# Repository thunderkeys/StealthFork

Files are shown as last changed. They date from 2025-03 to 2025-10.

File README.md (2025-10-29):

# Stealth Fork (Beta)  

<p align="center">
The one where Micron R1 & Salad Fork had a baby...
</p>

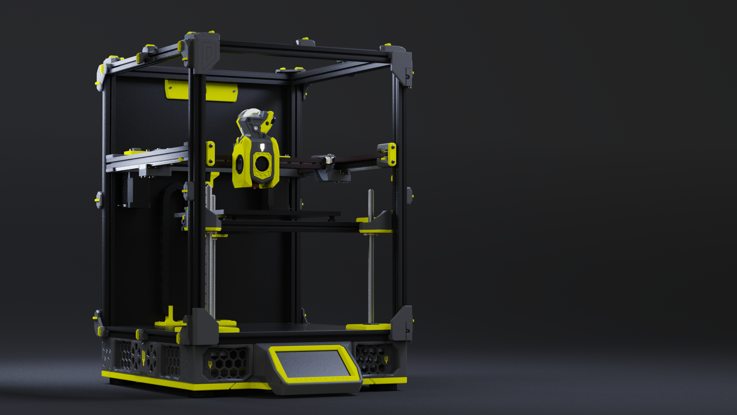
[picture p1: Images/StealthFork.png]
Rendering of a StealthFork


<p align="center">
  <a aria-label="Stars" href="https://github.com/PrintersForAnts/StealthFork/stargazers">
    </a> &nbsp;
    
  <a aria-label="Forks" href="https://github.com/PrintersForAnts/StealthFork/network/members">
    </a> &nbsp;
    
  <a aria-label="License" href="https://github.com/PrintersForAnts/StealthFork/blob/main/LICENSE">
    </a> &nbsp;
    
  <a aria-label="Commits" href="https://github.com/PrintersForAnts/StealthFork/commits/main">
    </a> &nbsp;
    
  <a aria-label="Discord" href="https://discord.gg/doomcube">
    </a>
</p>

## About  

Stealth Fork is an experimental design that blends the awesome aesthetic and compact form factor of the [**Micron+ R1**](https://github.com/PrintersForAnts/Micron/tree/main) with the fixed gantry of the [**Salad Fork**.](https://github.com/PrintersForAnts/Salad_Fork) If you’ve ever wanted a machine that blends the best of both, this is it.  

### Additional Features Ported from Micron:
- Bottom panel as stock
- Dual shear add-ons for A/B motors
- Pinned variants of A/B & X/Y as stock
- Optimised belt path
- Larger feet for more stability
- 3.5-inch / 4.3-inch display mounts as stock
- 2x Keystone mounts in rear skirt
- Stealthy aesthetics

> **Note:** This repository is a work in progress. I'll be updating it as things evolve. The goal is a seamless build experience, without compromising the high standards of either parent design.  

---

## Current Status  

- ✅ **STLs Uploaded** – All required STLs for a 180mm or 160mm build are included.
- 🔜 **CAD Files Coming Soon** – Once files are cleaned up, they'll be added (Skirt CAD files available).
- ⚠️ **Beta Release** – While all parts have been printed successfully, a full assembly is still pending. Expect minor refinements.

---

## Required Parts from Micron R1

Some parts are not included in this repo and need to be pulled directly from the **Micron R1 Repo** to convert your current Salad Fork. This is intended to prevent having to update several files that can be used for both printers. However, this may change and they all get uploaded here if it becomes too much of a pain based on feedback. 

| **Category** | **Micron R1 Repo Link** | **Required Parts** |
|---|---|---|
| **Panel Clips & Misc** | [Panels](https://github.com/PrintersForAnts/Micron/tree/main/STLs/Panels) | All except: Bowden Entry Accent Front Cover, Top Hinge Leaf |
| **X Axis** | [X Axis](https://github.com/PrintersForAnts/Micron/tree/main/STLs/Gantry/X_Axis) | All |
| **AB Double Shear Mounts** | [AB Drives](https://github.com/PrintersForAnts/Micron/tree/main/STLs/Gantry/AB_Drives/double_shear_mounts) | All |
| **Front Skirt Display Mounts** | [Skirt Displays](https://github.com/PrintersForAnts/Micron/tree/main/STLs/Skirts/Displays) | All except: Bezels |
| **Front Idler Carrier** | [Idler Carrier](https://github.com/PrintersForAnts/Micron/tree/main/STLs/Gantry/Idlers) | Screwed or Pinned available |

---

## Print Recommendations

**All STLs should be correctly oriented for printing.**

- **Material**: ABS or ASA
- **Infill**: 40% (Grid, Gyroid, Honeycomb, Triangle or Cubic)
- **Supports**: Not required
- **Layer Height**: 0.2mm (Including first layer)
- **Wall Count**: 4
- **Extrusion Width**: Forced 0.4mm
- **Solid Top/Bottom Layers**: 5

---

## BOM

A full BOM will be provided, but for now, the large differences are:

|**Item**|**Qty**|**Link**|**Notes**|
|---|---|---|---|
|Feet|x4|[Ali Express](https://s.click.aliexpress.com/e/_EJ0t67E)|
|Waveshare 4.3 Display|x1|[Ali Express](https://s.click.aliexpress.com/e/_EGOmTWc)|
|M5x20 BHCS|x4|[Ali Express](https://s.click.aliexpress.com/e/_ExQz6rS)|
|M3x8 BCHS|x40~|[Ali Express](https://s.click.aliexpress.com/e/_EyFT87W)|To replace M3x6 BHCS for skirt mounting, and replace M3x10 BHCS on gantry mounting.|
|M3x12 BHCS|x25~|[Ali Express](https://s.click.aliexpress.com/e/_Ew2GXKg)|For mounting bottom panel to skirts.|
|M3x25 BHCS|x3|[Ali Express](https://s.click.aliexpress.com/e/_ExoTSVa)|To mount skirt corners.|
|M3x20 BHCS|x1|[Ali Express](https://s.click.aliexpress.com/e/_Eu5EjP6)|To mount power inlet corner.|

---

## Feedback & Discussion  

If you're building a Stealth Fork, I'd love to hear your thoughts! 

Join the discussion, suggest improvements, or share feedback in the 'stealth_fork' channel on the Doomcube Discord.  

---

## Raising Issues

If you encounter any issues, please report them via the Issues section on the Git repository. 

Be as detailed as possible — include steps to reproduce and any relevant screenshots. 

Your feedback helps improve the Stealth Fork for everyone!

---

## Version History

| Date | Changes |
|---|---|
| 28-Oct-2025  | `[a]_Z_Bed_Mount_Front_L_x1.stl` & `[a]_Z_Bed_Mount_Front_R_x1.stl` updated to remove interferance with extrusion. |
| 27-Mar-2025  | Added STLs & CAD to convert Salad Fork rear panel to StealthFork Bowden entry. |
| 19-Mar-2025  | Fixed bottom panel DXFs. *(Thanks TurtleCrawler)* |
| 18-Mar-2025  | Uploaded bottom panel STLs & DXFs for 180mm & 160mm builds |
| 15-Mar-2025  | Uploaded 160mm skirt STLs<br>Uploaded 160_Skirts_v16.step<br>Uploaded 180_Skirts_v24.step<br>Added missing Rear_Centre_Skirt_Keystone_x1.stl (180mm) |
| 10-Mar-2025  | Initial release of beta STLs |

---

## Acknowledgements

- **HartK** for the awesome Micron  
- **Yeri** for the equally awesome Salad Fork
- **Thunderkeys** for his help with various STL issues

---

## Build Showcase

### **TurtleCrawler**

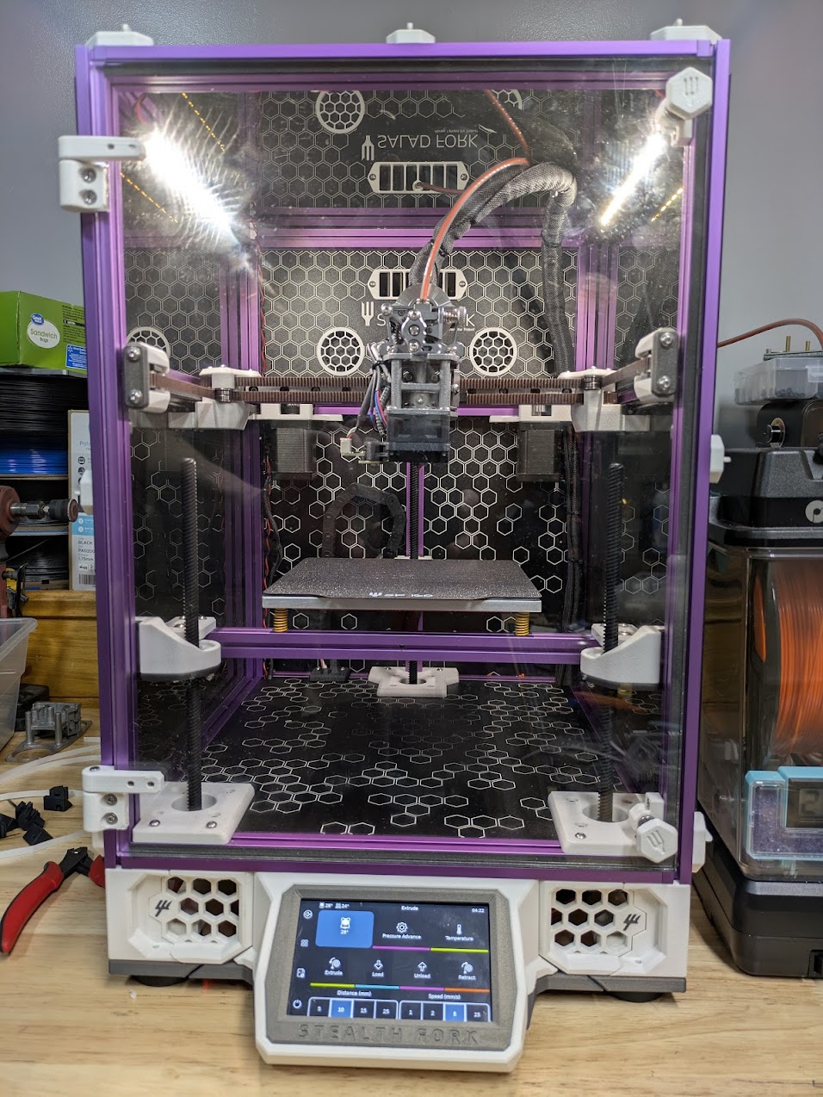
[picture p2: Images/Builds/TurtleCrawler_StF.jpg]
Turtlecrawler_StF


### **Thunderkeys**

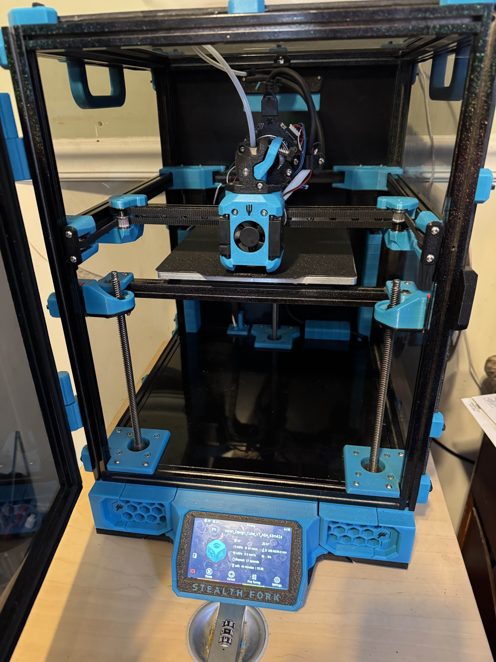
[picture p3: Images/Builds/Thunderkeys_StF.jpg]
Thunderkeys_StF


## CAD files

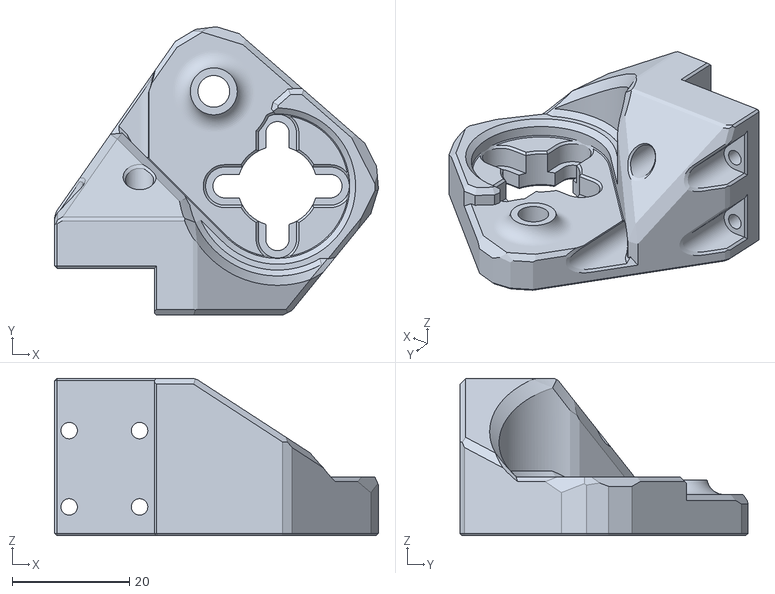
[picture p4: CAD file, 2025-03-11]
STLs/Z/Z_Carriage_Main_Left_x1.stl
55.2 x 49.2 x 26.8

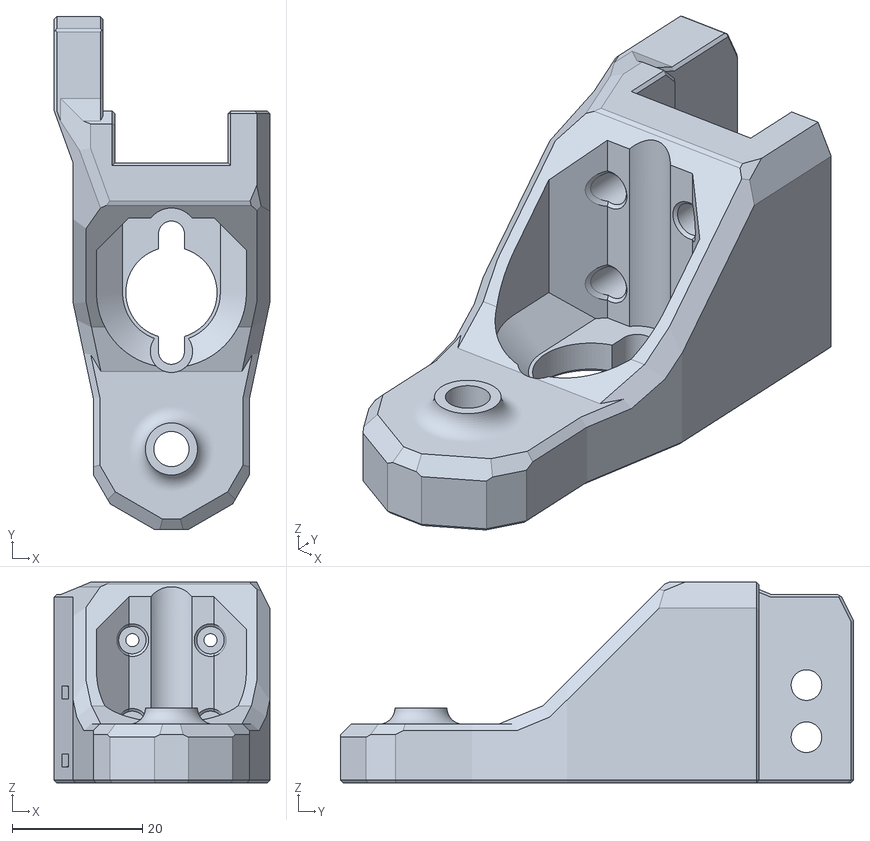
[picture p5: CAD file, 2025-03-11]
STLs/Z/Z_Carriage_Main_Rear_x1.stl
33.1 x 78.8 x 30.8

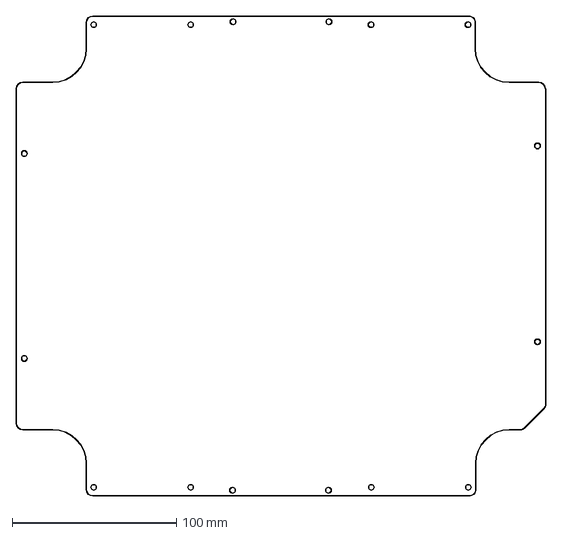
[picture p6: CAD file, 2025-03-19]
DXFs/160_Bottom_Panel.dxf
321.9 x 291.8 mm

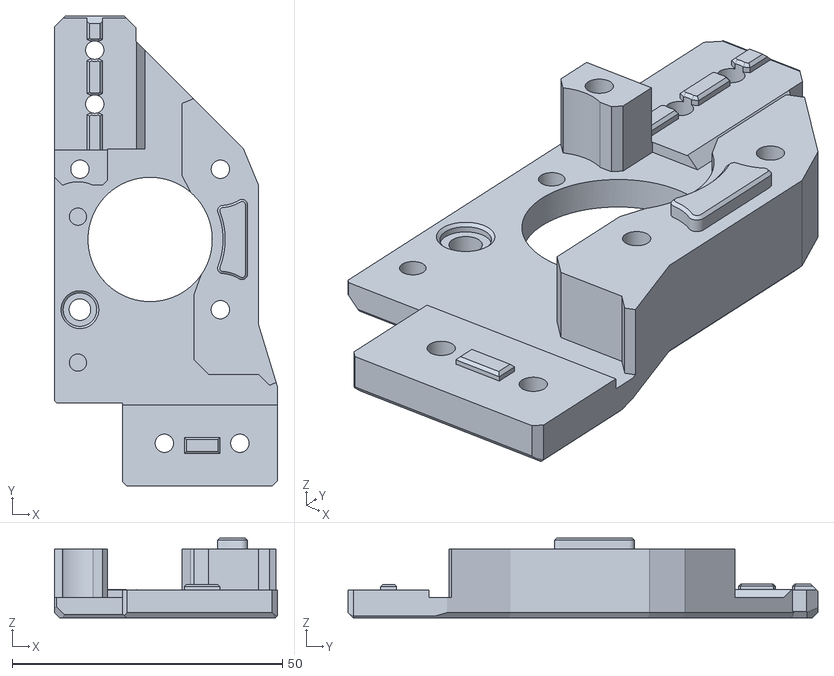
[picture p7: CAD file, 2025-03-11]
STLs/Gantry/A_B_Drives/B_Drive_Frame_Lower_Pinned.stl
41.3 x 87.0 x 14.8

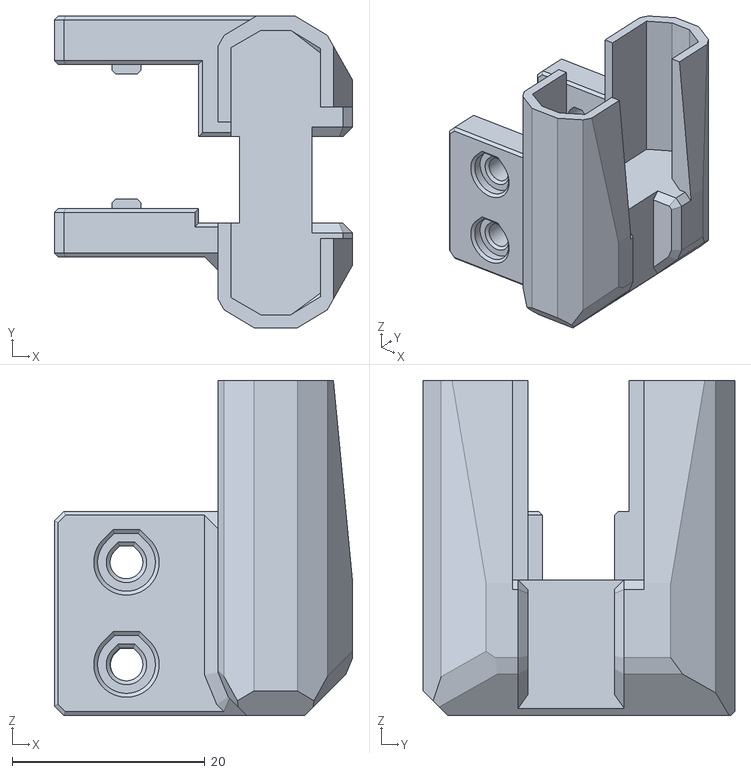
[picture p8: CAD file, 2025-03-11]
STLs/Gantry/Idler_Housing_x2.stl
31.0 x 32.4 x 34.8

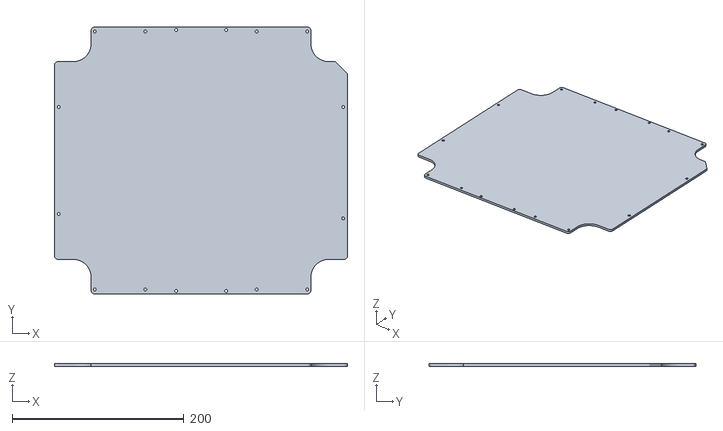
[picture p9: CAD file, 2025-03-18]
STLs/Panels/180_Bottom_Panel.stl
341.6 x 311.2 x 3.00

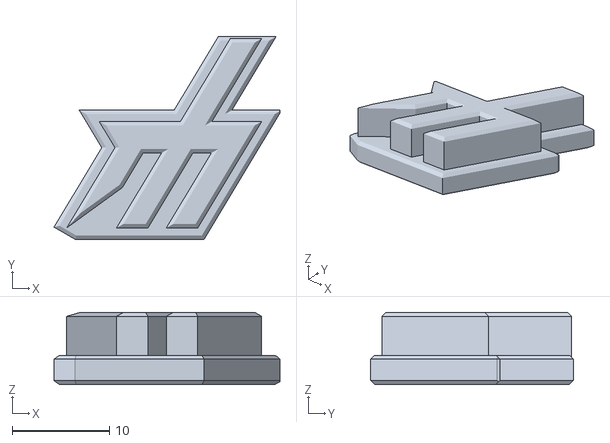
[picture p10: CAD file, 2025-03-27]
STLs/Panels/Salad Fork Rear Panel Conversion/Logo_Insert_x1.stl
23.2 x 20.8 x 7.40

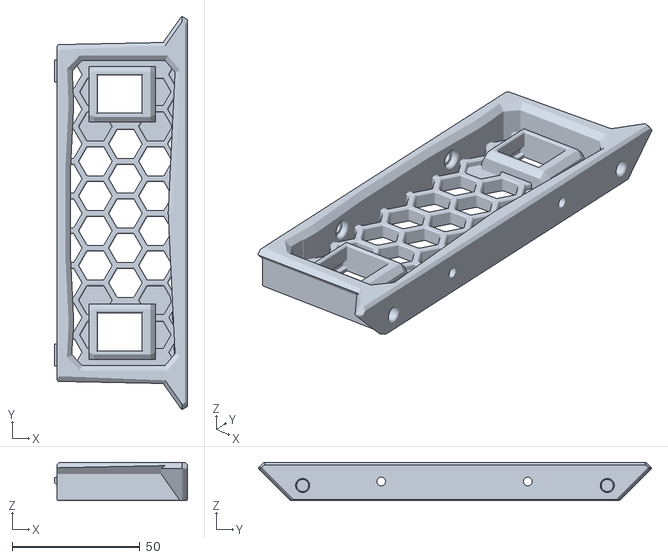
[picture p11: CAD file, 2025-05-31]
STLs/Skirts/160/160_Rear_Centre_Skirt_Keystone_x1.stl
52.0 x 153.8 x 15.0

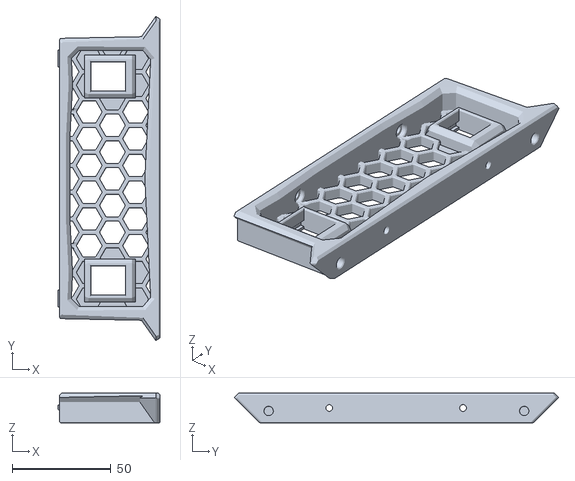
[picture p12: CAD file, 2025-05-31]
STLs/Skirts/180/Rear_Centre_Skirt_Keystone_x1.stl
52.0 x 164.4 x 15.0

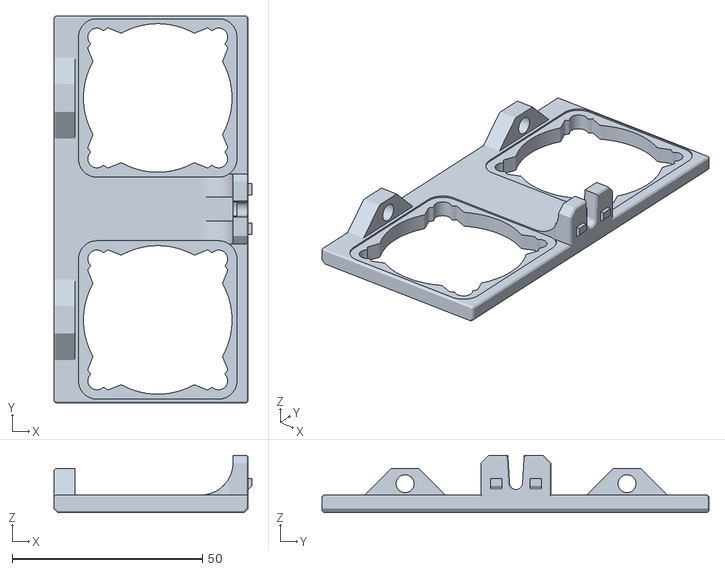
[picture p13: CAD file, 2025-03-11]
STLs/Skirts/Common STLs/Centre_Skirt_Fan_Mount_x2.stl
52.0 x 101.5 x 15.0

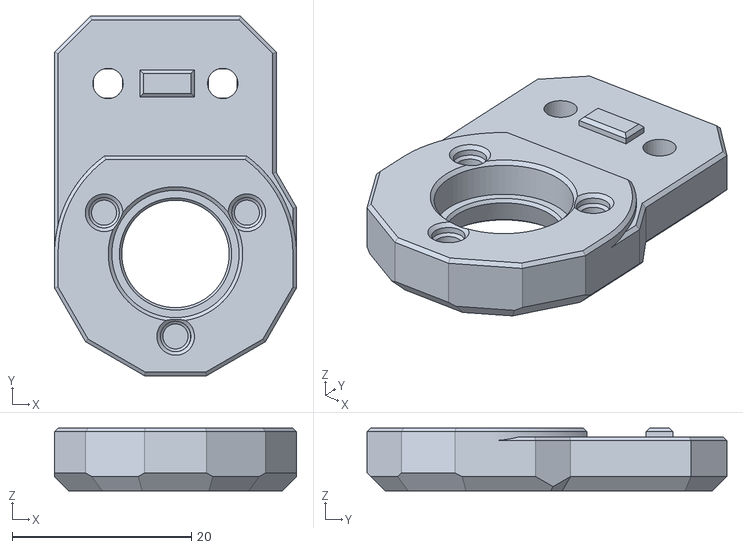
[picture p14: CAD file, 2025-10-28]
STLs/Z/[a]_Z_Bed_Mount_Front_L_x1.stl
27.0 x 40.1 x 7.00

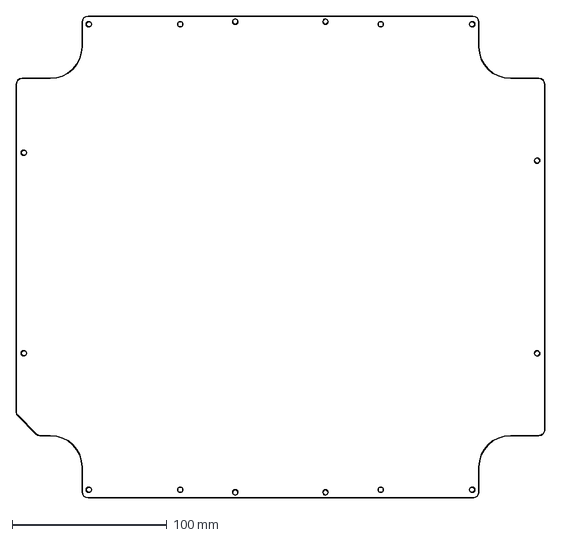
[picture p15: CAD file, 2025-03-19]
DXFs/180_Bottom_Panel.dxf
341.6 x 311.2 mm

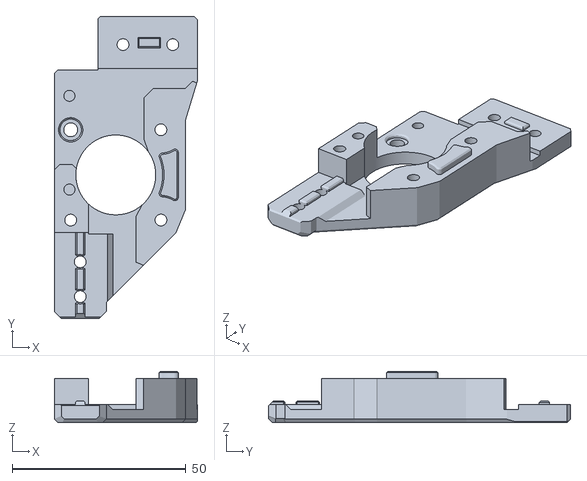
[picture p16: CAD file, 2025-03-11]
STLs/Gantry/A_B_Drives/A_Drive_Frame_Lower_Pinned.stl
41.3 x 87.0 x 14.8

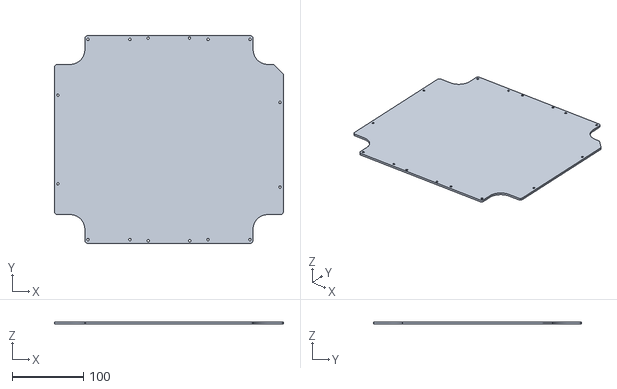
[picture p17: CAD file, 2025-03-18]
STLs/Panels/160_Bottom_Panel.stl
321.9 x 291.8 x 3.00

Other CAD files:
STLs/Z/Z_Carriage_Main_Right_x1.stl
STLs/Panels/Salad Fork Rear Panel Conversion/[a]_Bowden_Tube_Entry_Accent_Cover_x1.stl
STLs/Skirts/160/160_Corner_A_Front_Skirt _x1.stl
STLs/Skirts/180/[a]_Corner_B_Side_Skirt_Accent_x2.stl
STLs/Gantry/A_B_Drives/A_Drive_Frame_Lower_Screwed.stl
STLs/Gantry/A_B_Drives/A_Drive_Frame_Upper_Pinned.stl
STLs/Gantry/A_B_Drives/A_Drive_Frame_Upper_Screwed.stl
STLs/Gantry/A_B_Drives/B_Drive_Frame_Lower_Screwed.stl
STLs/Gantry/A_B_Drives/B_Drive_Frame_Upper_Pinned.stl
STLs/Gantry/A_B_Drives/B_Drive_Frame_Upper_Screwed.stl
STLs/Panels/Bowden_Entry_Logo_Insert_x1.stl
STLs/Panels/Salad Fork Rear Panel Conversion/Bowden Tube Entry Rear Cover Base_x1.stl
STLs/Panels/Salad Fork Rear Panel Conversion/Bowden Tube Entry Rear Cover ECAS_x1.stl
STLs/Panels/Salad Fork Rear Panel Conversion/Bowden Tube Entry Rear Cover M10_x1.stl
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

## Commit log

2025-03-11 Upload beta files
    Initial upload of 180mm beta files.
    [A_Drive_Frame_Lower_Pinned.stl, A_Drive_Frame_Lower_Screwed.stl, A_Drive_Frame_Upper_Pinned.stl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]
2025-03-15 Upload 160mm Skirts Stls & Skirts CAD
    [160_Corner_A_Front_Skirt _x1.stl, 160_Corner_A_Side_Skirt_x2.stl, 160_Corner_B_Front_Rear_Skirt_x2.stl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]
2025-03-18 Add bottom panels
    Uploaded STLs & DXFs for 160 & 180 bottom panels
    [160_Bottom_Panel.dxf, 160_Bottom_Panel.stl, 180_Bottom_Panel.dxf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]
2025-03-19 Fixed bottom panel DXFs
    [160_Bottom_Panel.dxf, 180_Bottom_Panel.dxf]
2025-03-27 Add SaladFork Rear Panel Conversion STLs & CAD.
    [Bowden Tube Entry Rear Cover Base_x1.stl, Bowden Tube Entry Rear Cover ECAS_x1.stl, Bowden Tube Entry Rear Cover M10_x1.stl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]
2025-05-27 Redo rear keystone skirt pieces with keystone cutters from Voron Construct
    [160_Rear_Centre_Skirt_Keystone_x1.stl, Rear_Centre_Skirt_Keystone_x1.stl]
2025-10-28 Update Z Bed Mount STLs
    Removed an area of plastic from `[a]_Z_Bed_Mount_Front_L_x1.stl`, & [a]_Z_Bed_Mount_Front_R_x1.stl` that was interfering with the front bed extrusion.
    [[a]_Z_Bed_Mount_Front_L_x1.stl, [a]_Z_Bed_Mount_Front_Left_x1.stl, [a]_Z_Bed_Mount_Front_R_x1.stl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]
